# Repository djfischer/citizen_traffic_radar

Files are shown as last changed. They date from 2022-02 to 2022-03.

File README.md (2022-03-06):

# Citizen Traffic Monitor

This is a simple traffic monitoring device that uses a Raspberry Pi for acquiring the traffic data. It
utilizes a compact doppler radar to monitor a roadway and captures bi-directional vehicle counts and speeds.
The device can operate continuously as a service and is able to upload the data to the cloud via a simple 
USB 4G stick. An optional camera is added to the device for security purposes and can be used to capture a 
street view.

## History 
Our neighborhood is situated between two artierial steets and receives significant cut-through traffic.
Concerned citizens have formed a neighborhood association and this device was built to help the 
association understand vehicle traffic volumes and patterns. 

## Hardware
Other hardware could be used, but here is what the subject device is built with:
 * [Raspberry Pi 3B+] - https://www.raspberrypi.com/products/raspberry-pi-3-model-b-plus/ ~$35
 * [Omnipresence OPS-243A doppler radar sensor] - https://omnipresense.com/product/ops243-doppler-radar-sensor/ ~$209
 * [Arducam 8MP Noir camera for Raspberry Pi] https://www.uctronics.com/arducam-noir-8mp-sony-imx219-camera-module-with-cs-lens-2717-for-raspberry-pi.html] ~$60
 * [Polycase WQ-48 hinged waterproof enclosure & mounting panel]  - https://www.polycase.com/wq-48 & https://www.polycase.com/wq-48p ~ $35 & $3.50 
 * [4G WiFi USB Mobile Modem] https://smile.amazon.com/dp/B08NX14VQZ?psc=1&ref=ppx_yo2_dt_b_product_details ~$36
 * [Optional - Voltaic Systems V50 USB battery pack for backup power] - https://voltaicsystems.com/amp/v50/ ~$65
 * 3D printed mounts for Raspberry Pi, OpS-243A Doppler Radar, USB modem, camera, and for mounting unit onto a pole made from electrical conduit
 * Various fasteners
 * Various USB Cables

## Cloud
As built, the device uploads data to a Cloud of your choice using rclone and crontab

## Known Issues
There are a a few issues with the current build:
 * The OPS-243A radar card connects to the Raspberry Pi via USB. This USB connection can drop, so a simple
   routine was developed to check the status of this connection every 5  minutes via a shell script and
   crontab. If the connection drops, the Raspberry Pi is rebooted
 * As the device must be located off the monitored roadway, there is a cosine correction that could be
   applied to the detected speeds. As the mounting position will typically result in a small incident
   angle, this correction is currently ignored in the acquisition software.

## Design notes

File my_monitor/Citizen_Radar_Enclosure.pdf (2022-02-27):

## Layout of Enclosure for Citizen Traffic Monitor

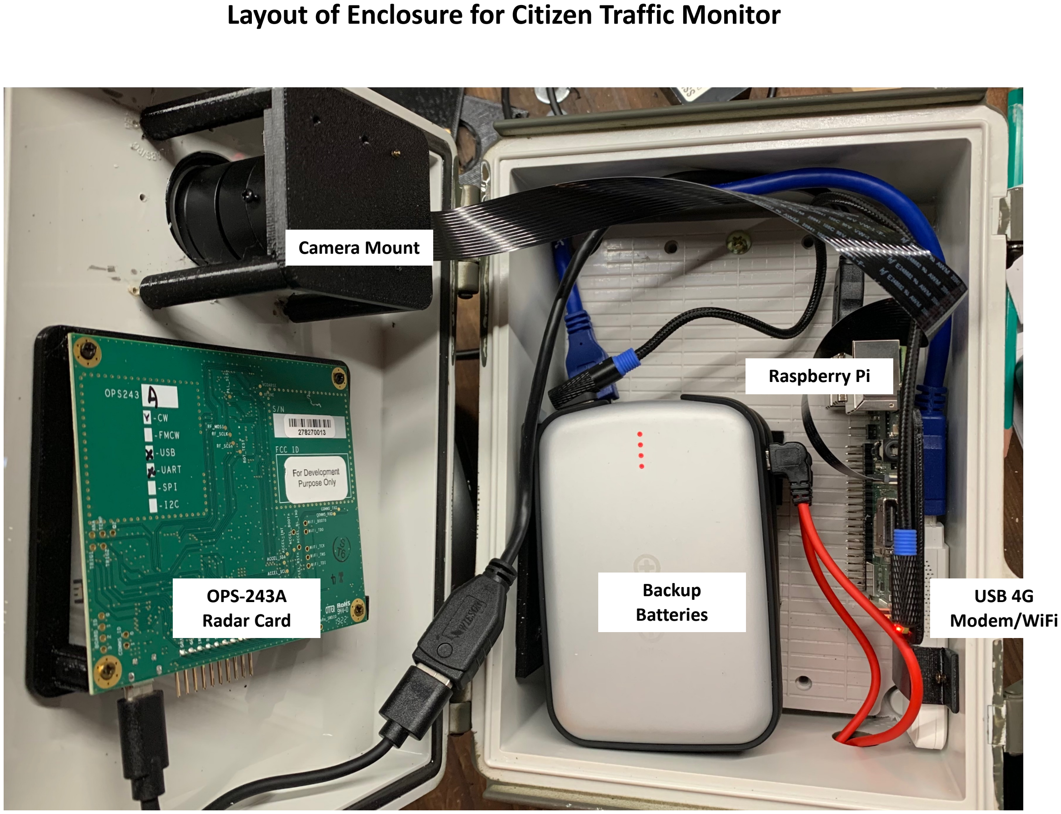
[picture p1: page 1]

OPS-243A
Radar Card

Camera Mount

Backup
Batteries

Raspberry Pi

USB 4G
Modem/WiFi

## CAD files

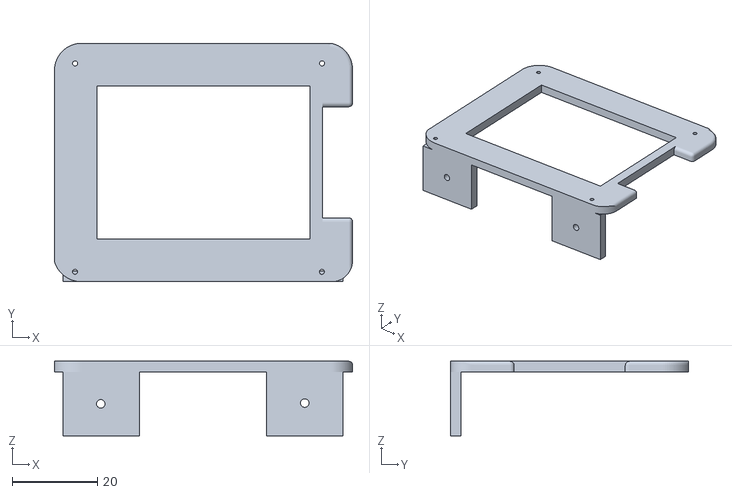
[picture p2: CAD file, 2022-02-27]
my_monitor/3D_Print_Files/RPI_Mount_w_cutout.stl
70.0 x 56.0 x 17.5

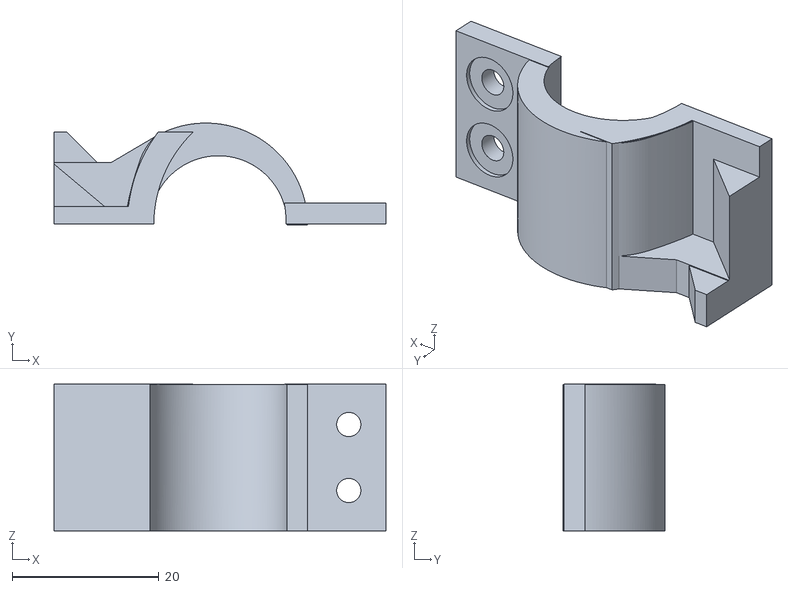
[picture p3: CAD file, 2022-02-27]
my_monitor/3D_Print_Files/L_Pole_Mount_Bracket_v2.stl
45.2 x 13.9 x 20.0

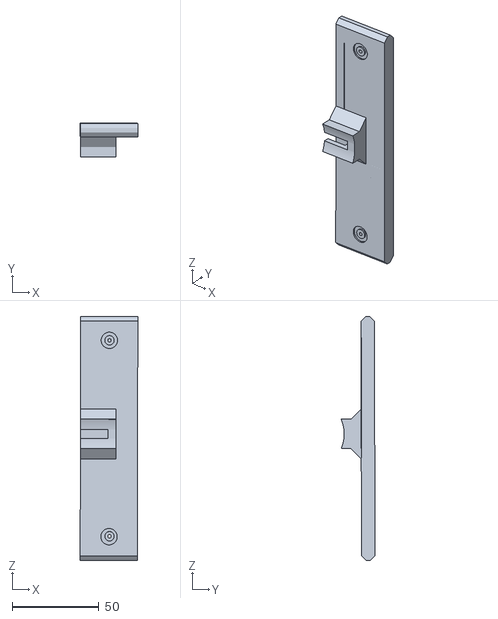
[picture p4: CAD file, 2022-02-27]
my_monitor/3D_Print_Files/Mnt_bracket_flat_scaled_1.32.stl
33.3 x 19.5 x 140.7

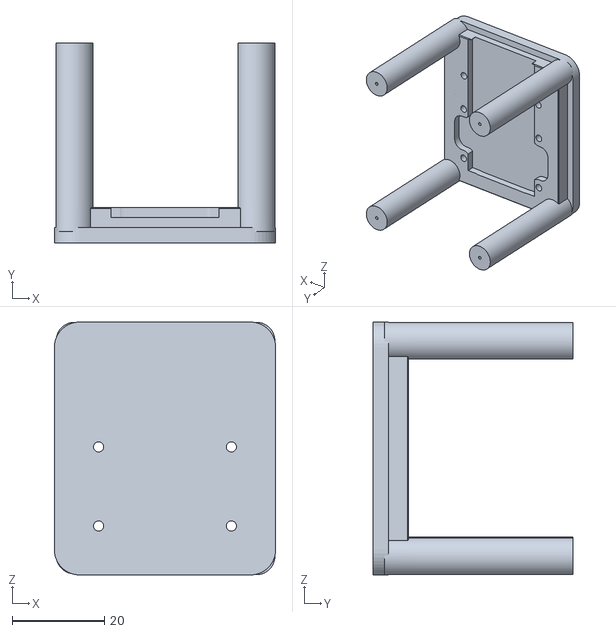
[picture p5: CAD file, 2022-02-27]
my_monitor/3D_Print_Files/Camera_Mount.stl
48.0 x 43.3 x 54.8

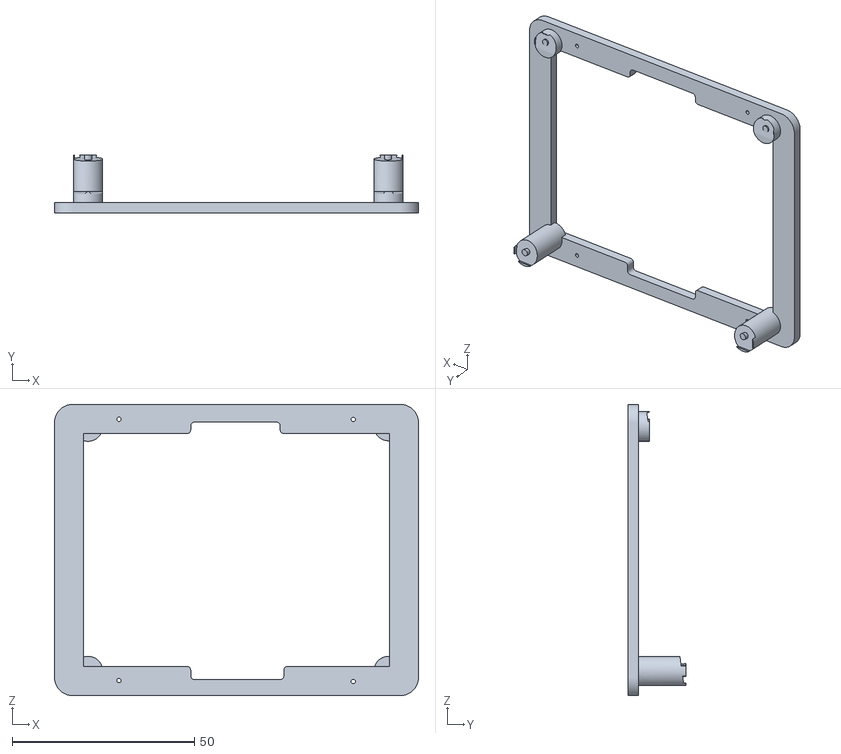
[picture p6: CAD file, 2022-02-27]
my_monitor/3D_Print_Files/OPS_Mount.stl
100.0 x 15.9 x 80.0

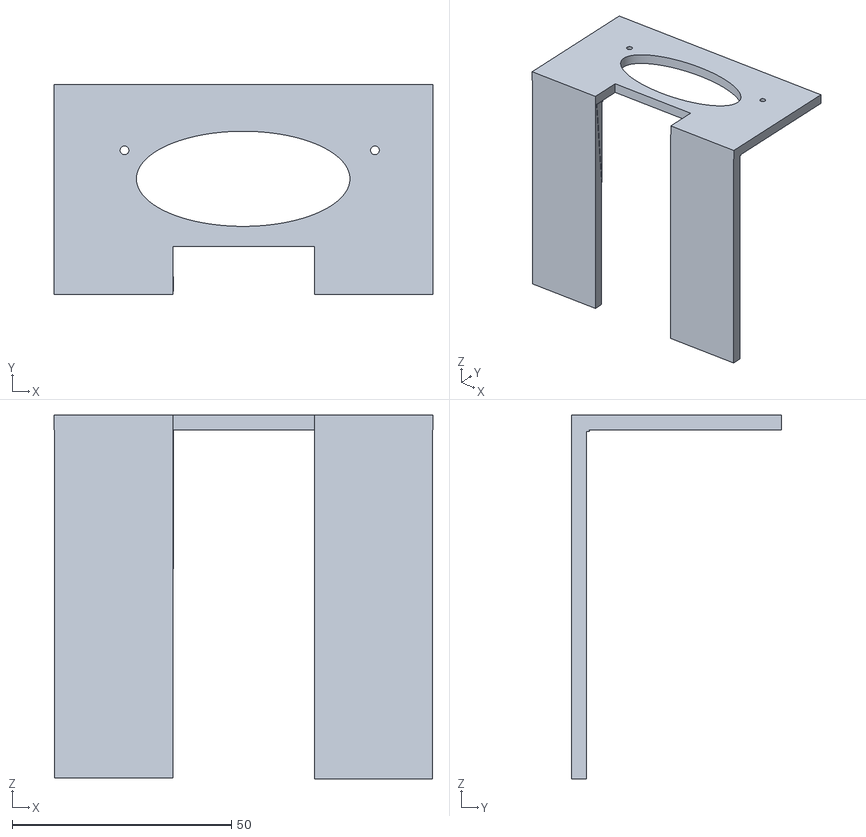
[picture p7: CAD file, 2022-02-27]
my_monitor/3D_Print_Files/Battery_Pack_Mount_1.35.stl
86.4 x 47.8 x 82.9

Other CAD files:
my_monitor/3D_Print_Files/R_Pole_Mount_Bracket_v2.stl

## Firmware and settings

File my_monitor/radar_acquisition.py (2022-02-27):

#!/usr/bin/env python3
####################################################
#
# Description: Python code to acquire and output data
# Omnipresesence OPS-243A radar card. Code has borrowed
# elements from Github omnipresense python_utilities
# https://github.com/omnipresense/python_utilities
# amattas / speedtrap - https://github.com/amattas/speedtrap 
# and a simple radar sign:
# https://www.instructables.com/Low-Cost-Radar-Speed-Sign/
#####################################################


# Modifiable parameters
# Ops243 module settings:
Ops243_Speed_Report = 'OS'
Ops243_Range_Report_Off = 'Od'
Ops243_Speed_Output_Units = 'US'
Ops243_Direction_Control = 'R|'
Ops243_Sampling_Frequency = 'S2'
Ops243_Data_Precision = 'F2'
Ops243_Transmit_Power = 'PX'
Ops243_Data_Precision = 'F2'
Ops243_Blank_Data_Reporting = 'BZ'
Ops243_json_Reporting = 'OJ'
Ops243_Magnitude_Reporting = 'OM'
Ops243_Radar_Sign_Reporting = 'ON'


# Imports
import os
import sys
import time
import datetime
from decimal import *
import serial
import RPi.GPIO as GPIO
import re
import pandas as pd
import numpy as np
import json
from PIL import Image, ImageDraw, ImageFont
import subprocess

# Photo routine based off detected vehicle speed

def take_photo(name):
# Using raspistill legacy, but could shift to libcamera    
    cmd = "raspistill --width 3280 --height 2464 --exposure sports --ev 0.5 -n -t 600 --timelapse 500 -o "+name+"_%d.jpg"
    subprocess.run(cmd, shell = True)
    return(name)

def annotate_photo(name):
    print("annotate photo entered")
    font = ImageFont.truetype(r'/home/pi/python/camera/bebas/Bebas-Regular.ttf', 64)
    image = Image.open(name)
    basename = os.path.basename(name)
    print(basename)
    myfields = basename.split('_')
    pdate = myfields[0]
    ptime = myfields[1]
    ptime=ptime.replace('-',':')
#    print('ptime after replace: ',ptime)
    tempspeed = myfields[2].split('.')
    pspeed = tempspeed[0]+'.'+tempspeed[1]
    pic_string = 'Date:'+pdate+'  Time:'+ptime+'  Speed:'+pspeed
    print(pic_string)
# set image width
    width, height = image.size 
    draw = ImageDraw.Draw(image)
    text = pic_string
    textwidth, textheight = draw.textsize(text)
    ymargin = 100
    xmargin = 850
    x = width - textwidth - xmargin
    y = height - textheight - ymargin
    draw.text((x, y), text,(0,0,0),font=font)
    image.save(name)
    return(name)   

# Initialize the USB port to read from the OPS-243A module
ser=serial.Serial(
    port = '/dev/ttyACM0',
    baudrate = 9600,
    parity = serial.PARITY_NONE,
    stopbits = serial.STOPBITS_ONE,
    bytesize = serial.EIGHTBITS,
    timeout = 1,
    writeTimeout = 2
)
ser.flushInput()
ser.flushOutput()

# sendSerialCommand: function for sending commands to the OPS-243A module
def sendSerCmd(descrStr, commandStr) :
    data_for_send_str = commandStr
    data_for_send_bytes = str.encode(data_for_send_str)
    print(descrStr, commandStr)
    ser.write(data_for_send_bytes)
    # Initialize message verify checking
    ser_message_start = '{'
    ser_write_verify = False
    # Print out module response to command string
    while not ser_write_verify :
        data_rx_bytes = ser.readline()
        data_rx_length = len(data_rx_bytes)
        if (data_rx_length != 0) :
            data_rx_str = str(data_rx_bytes)
            if data_rx_str.find(ser_message_start) :
                print(data_rx_str)
                ser_write_verify = True

# Initialize and query Ops243A Module
print("\nInitializing Ops243A Module")
sendSerCmd("\nSet Speed Speed Report: ", Ops243_Speed_Report)
time.sleep(1.2)
sendSerCmd("\nSet Speed Speed Report: ", Ops243_Range_Report_Off)
time.sleep(1.2) 
sendSerCmd("\nSet Speed Output Units: ", Ops243_Speed_Output_Units)
time.sleep(2)
sendSerCmd("\nSet Speed Speed Report: ", Ops243_Speed_Report)
time.sleep(1.2)
sendSerCmd("\nSet Direction Control: ", Ops243_Direction_Control)
time.sleep(1.2)
sendSerCmd("\nSet Sampling Frequency: ", Ops243_Sampling_Frequency)
time.sleep(1.2)
sendSerCmd("\nSet Transmit Power: ", Ops243_Transmit_Power)
time.sleep(1.2)
sendSerCmd("\nSet Data Precision: ", Ops243_Data_Precision)
time.sleep(1.2)
sendSerCmd("\nSet Blank Data Reporting: ", Ops243_Blank_Data_Reporting)
time.sleep(1.2)
sendSerCmd("\nSet Json_Reporting: ", Ops243_json_Reporting)
time.sleep(1.2)
sendSerCmd("\nSet Magnitude_Reporting: ", Ops243_Magnitude_Reporting)
time.sleep(1.2)

ser=serial.Serial(
    port = '/dev/ttyACM0',
    baudrate = 9600,
    parity = serial.PARITY_NONE,
    stopbits = serial.STOPBITS_ONE,
    bytesize = serial.EIGHTBITS,
    timeout = 0.01,
    writeTimeout = 2
    )

# Speed limit display loop
done = False
# Flush serial buffers
ser.flushInput()
ser.flushOutput()
# Reset timers
start_time = time.time()
current_time = start_time
delta_time = 0.0
# Initial state 
speed_max = 0.0
speed_Limit = 25.0
speed_Lim_Offset = 5
speed_cut_low=8.0
daily_speed=[]
daily_mag=[]
daily_time=[]
daily_count=[]
lst_size = 180000
lst_speed = 0
spd_delta = 0
spd_counter = 0
df_north = pd.DataFrame()
df_south = pd.DataFrame()
now = datetime.datetime.now()

counter = 0


#last_date = None
cur_Hr = datetime.datetime.now().hour
cur_Min = datetime.datetime.now().minute
cur_Sec = datetime.datetime.now().second
cur_Day = datetime.datetime.now().day
cur_Mo = datetime.datetime.now().month
cur_Yr = datetime.datetime.now().year
last_date = datetime.datetime(year=cur_Yr,month=cur_Mo,day=cur_Day,hour=23,minute=59,second=59)

print('current hour is: ',cur_Hr)

while True:
    today=datetime.datetime.now()
#    today=datetime.datetime.now().minute
    cur_day = today.strftime("%Y-%m-%d %H:%M:%S")
    print('date is: ',cur_day)

    while not done:
        time.sleep(.10)
        # Check for speed info from OPS243-A
        speed_available = False
        spd=0
        mag=0
        Ops243_rx_float = 0.0
        try:
             Ops243_rx_bytes = ser.readline()
             Ops243_rx_bytes_length = len(Ops243_rx_bytes)
        except:
             pass

        if(Ops243_rx_bytes_length != 0) :
             try:
                 current_report_json = json.loads(Ops243_rx_bytes)
                 Ops243_rx_float = float(current_report_json['speed'])
                 mag = float(current_report_json['magnitude'])
                 speed_available = True
             except:
                 pass

             if speed_available == True :
                 now = datetime.datetime.now()
                 spd = Ops243_rx_float
                 if counter >= 1:
                    spd_delta = spd - lst_speed
                    lst_speed = spd
                 if abs(spd_delta) >= speed_cut_low:
                    spd_counter = spd_counter + 1
        if abs(spd) > speed_cut_low:
            print('time, speed, and magnitude  are: ', now, spd,mag)
            daily_speed.append(spd)
            daily_mag.append(mag)
            daily_time.append(now.strftime("%Y-%m-%d %H:%M:%S.%f"))
            daily_count.append(spd_counter)
            if spd > speed_max :
                speed_max = spd
                start_time = today=datetime.datetime.now()
                current_time = start_time
            else :
                current_time = datetime.datetime.now()
        else :
            current_time =datetime.datetime.now()
        if abs(spd) > speed_Limit+speed_Lim_Offset:
            cur_Day = datetime.datetime.now().day
            cur_Mo = datetime.datetime.now().month
            cur_Yr = datetime.datetime.now().year
            cur_Hr = datetime.datetime.now().hour
            cur_min = datetime.datetime.now().minute
            cur_sec = datetime.datetime.now().second
            cur=datetime.datetime.now().strftime('%Y-%m-%d_%H:%M:%S.%f')[:-4]
# Setup and take photo
            date_str = str(cur)+'_'+str(spd)
            file_name= '/opt/ramdisk/'+date_str
            take_photo(file_name)
            
        cur_Day = datetime.datetime.now().day
        cur_Mo = datetime.datetime.now().month
        cur_Yr = datetime.datetime.now().year
        cur_Hr = datetime.datetime.now().hour
        cur_min = datetime.datetime.now().minute
        cur_sec = datetime.datetime.now().second
        dayTripper = cur_Hr + cur_min/60 + cur_sec/3600
        if counter==12600 or dayTripper >= 23.96:
#        if last_date < today:
            last_date = datetime.datetime(year=cur_Yr,month=cur_Mo,day=cur_Day,hour=23,minute=59,second=59)
            df = pd.DataFrame(data =[daily_time,daily_speed,daily_mag,daily_count])
            df=df.transpose()
            df.columns=['date_sp','speed','magnitude','vehicle_cnt']
            df['date']=pd.to_datetime(df['date_sp'],format="%Y-%m-%d %H:%M:%S.%f")
            df.index=df['date']
            df['speed'] = pd.to_numeric(df['speed'])
            df['magnitude'] = pd.to_numeric(df['magnitude'])
            print(df.speed.describe())
            
            if not df.empty:
                df = df.drop('date',axis=1)
                df = df.drop('date_sp',axis=1)
                df_south=df.loc[(df['speed'] >= speed_cut_low) & (df['speed'] <= 80)]
                df_north=df.loc[(df['speed'] <= -speed_cut_low) & (df['speed'] >= -80)]      

#           write out speeds to csv file
            date_str = str(cur_Yr)+'-'+str(cur_Mo)+'-'+str(cur_Day)+'_'+str(cur_Hr)+'-'+str(cur_min)
            filename='/home/pi/python/radar/'+date_str+'.csv'
            filenamen='/home/pi/python/radar/'+date_str+'n'+'.csv'
            filenames='/home/pi/python/radar/'+date_str+'s'+'.csv'
            if not df.empty:
                df.to_csv(filename, index=True,header=True,date_format='%m/%d/%Y %H:%M:%S.%f')
            if not df_south.empty:
                df_south.to_csv(filenames, index=True,header=True,date_format='%m/%d/%Y %H:%M:%S.%f')
            if not df_north.empty:
                df_north.to_csv(filenamen, index=True,header=True,date_format='%m/%d/%Y %H:%M:%S.%f')

            del daily_speed
            del daily_time
            del daily_mag
            del daily_count
            df=df[0:0]
            df_south=df_south[0:0]
            df_north=df_north[0:0]
            daily_speed=[]
            daily_mag=[]
            daily_time=[]
            daily_count=[]
            lst_speed = 0
            spd_counter = 0
            counter = 0
            daily_speed.append(0)
            daily_mag.append(0)
            daily_count.append(0)
            daily_time.append(now.strftime("%Y-%m-%d %H:%M:%S.%f"))
        counter=counter + 1

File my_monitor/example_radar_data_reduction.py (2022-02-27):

import requests
from bs4 import BeautifulSoup
import string
import json, ast
import dateutil.parser as dparser
from datetime import datetime, timezone, timedelta
from dateutil import relativedelta
import dateutil.parser
import numpy as np 
import pandas as pd
import matplotlib.pyplot as plt
import matplotlib.dates as mdates
from csv import writer
import scipy.stats
import ast
import math
from tabulate import tabulate
import plotly.graph_objects as go
import scipy.stats as stats
import io
import pylab
from itertools import groupby
from matplotlib.backends.backend_pdf import PdfPages
import random
import calendar

def groupSequence(x):
    it = iter(x)
    prev, res = next(it), []
  
    while prev is not None:
        start = next(it, None)
  
        if prev + 1 == start:
            res.append(prev)
        elif res:
            yield list(res + [prev])
            res = []
        prev = start
        
# Get today's date info
cur_Day = datetime.now().day
cur_Mo = datetime.now().month
cur_Yr = datetime.now().year

# Set speed units (mph or m/s)
spd_units = input("Enter speed units in mps or mph: ")
if spd_units == "mps" or spd_units == "MPS":
    spd_convert = 2.237
if spd_units == "mph" or spd_units == "MPH":
    spd_convert = 1.0

# Setup loop to get number of days to process....

# Get input from user on input data and traffic direction
fileNum = input("Enter number of days of Cherry speed data to process: ")

# Build file name list

dateStart = input("Enter date of starting file e.g. mm/dd/yyyy: ")

dateS = datetime.strptime(dateStart, "%m/%d/%Y").strftime("%Y-%m-%d")
print(dateS)
day = datetime.strptime(dateS, "%Y-%m-%d").strftime("%d")
month = datetime.strptime(dateS, "%Y-%m-%d").strftime("%m")
year = datetime.strptime(dateS, "%Y-%m-%d").strftime("%Y")
print(day,month,year)

print(calendar.monthrange(int(year), int(month)))
monthEnd = calendar.monthrange(int(year), int(month))
print(monthEnd[1])

dateS = datetime.strptime(dateStart, "%m/%d/%Y")
for i in range(0,int(fileNum)):
    loopDate = dateS + timedelta(days=i)
    newDate = loopDate.strftime("%-m-%-d")
    newDate_Yr = loopDate.strftime("%-Y-%-m-%-d")
    print(newDate,newDate_Yr)
    ifileN = '/Users/djfi/python/radar/cherry/'+newDate_Yr+'/'+newDate+'n.csv'
    ifileS = '/Users/djfi/python/radar/cherry/'+newDate_Yr+'/'+newDate+'s.csv'
    print(ifileN)
    print(ifileS)
    
# Loop to process North & South directions
    for j in range(0,2):  
# First fix-up input file to strip out extra header lines
        if j== 0:
            ifile = ifileN
            v_dir = 'n'
            direction_txt = "Northbound"
        if j== 1:
            ifile = ifileS
            v_dir = 's'
            direction_txt = "Southbound"
        counter = 0
        with open(ifile, "r+") as f:
            # First read the file line by line
            lines = f.readlines()
            # Go back at the start of the file
            f.seek(0)
            # Go back at the start of the file
            f.truncate()
            # Truncate file size
            for line in lines:
                if counter == 0:
                    f.write(line)
                if 'date,' not in line and counter > 0:
                    f.write(line)
                counter = counter + 1
        f.close()

# Read in, index and sort dataframe

        speed = pd.read_csv(ifile)
        print(speed)
        speed['date']=pd.to_datetime(speed['date'], format='%m/%d/%Y %H:%M:%S.%f')
        speed.index = speed['date']
        speed.sort_index(inplace=True)
        speed['speed']=abs(speed['speed'])

#Eliminate duplicates
# dropping duplicate values
        speed.drop_duplicates(subset=None, inplace=True)

        print('speed before rows2skip is: ',speed)
        print('')

# Convert speed
        speed['speed']=(spd_convert*speed['speed'])
        print('speed after conversion is: ',speed)

# Check for spurious max speed values

        mu = 0.0
        sigma = 2.75
        rand = np.random.normal(mu, sigma, 100)
        for idx, row in speed.iterrows():
            if  speed.loc[idx,'speed'] >52.0:
                vary = random.choice(rand)
                speed.loc[idx,'speed'] = vary + 52.0

        avg_speed = speed['speed'].mean()
        cnt_list = speed['vehicle_cnt'].tolist()
        spd_list = speed['speed'].tolist()
        date_list = speed['date'].tolist()

        acquisition_time = speed.index[0]
        acq_yr = acquisition_time.strftime("%Y")
        acq_mo = acquisition_time.strftime("%m")
        acq_day = acquisition_time.strftime("%d")


# Eliminate data noise spike at 0 reading  (for ops241 only 41.4 to 41.7)
        rows2skip=[]
#rows2skip = [idx for idx, val in enumerate (spd_list) if abs(val) >= 41.4 and abs(val) <= 41.8]
        rows2skip = [idx for idx, val in enumerate (spd_list) if abs(val) == 0.0]

        counter = 0
        for element in rows2skip:
            rows2skip[counter] = rows2skip[counter]+1
            counter = counter +1
# print('rows2skip after spike filtering is: ',rows2skip[counter-1])
        print(rows2skip)
        print('')

        print('/Users/djfi/python/radar/cherry/summaries/speed_rows_skip1'+'_'+str(acq_mo)+'-'+str(acq_day)+'-'+str(acq_yr)+'.csv')

#Write out noise-corrected data
        speed.to_csv('/Users/djfi/python/radar/cherry/summaries/speed_rows_skip1'+'_'+str(acq_mo)+'-'+str(acq_day)+'-'+str(acq_yr)+'.csv',index=False,date_format='%m/%d/%Y %H:%M:%S.%f')
        speed=speed[0:0]
        speed = pd.read_csv('/Users/djfi/python/radar/cherry/summaries/speed_rows_skip1'+'_'+str(acq_mo)+'-'+str(acq_day)+'-'+str(acq_yr)+'.csv',skiprows=rows2skip)
        #print('speed after rows2skip is: ',speed)
        speed['date']=pd.to_datetime(speed['date'], format='%m/%d/%Y %H:%M:%S.%f')
        speed.index = speed['date']
        speed.sort_index(inplace=True)

        cnt_list = speed['vehicle_cnt'].tolist()
        spd_list = speed['speed'].tolist()
        date_list = speed['date'].tolist()

        spd_delta=[]
        date_delta=[]

# Calculate deltas for speed and date data
        counter = 0    
        for element in spd_list:
            if counter == 0:
                spd_delta.append(0)
                date_delta.append(0)
            else:
                spd_delta.append(spd_list[counter] - spd_list[counter-1])
                del_mseconds=relativedelta.relativedelta(date_list[counter],date_list[counter-1]).microseconds/1000000
                del_seconds= relativedelta.relativedelta(date_list[counter],date_list[counter-1]).seconds
                del_minutes= relativedelta.relativedelta(date_list[counter],date_list[counter-1]).minutes
                del_minutes_secs = del_minutes*60.0
                secs_delt=del_minutes_secs+del_seconds+del_mseconds
                date_delta.append(secs_delt)
            counter = counter + 1

        print(len(spd_delta),len(date_delta))
#print(date_delta)
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
